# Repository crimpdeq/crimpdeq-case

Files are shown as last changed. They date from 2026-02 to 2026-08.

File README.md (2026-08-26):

# Crimpdeq 3D Case

OpenSCAD source files for the Crimpdeq 3D-printable enclosure (main body + lid), including assembly models and collision checks used in CI.

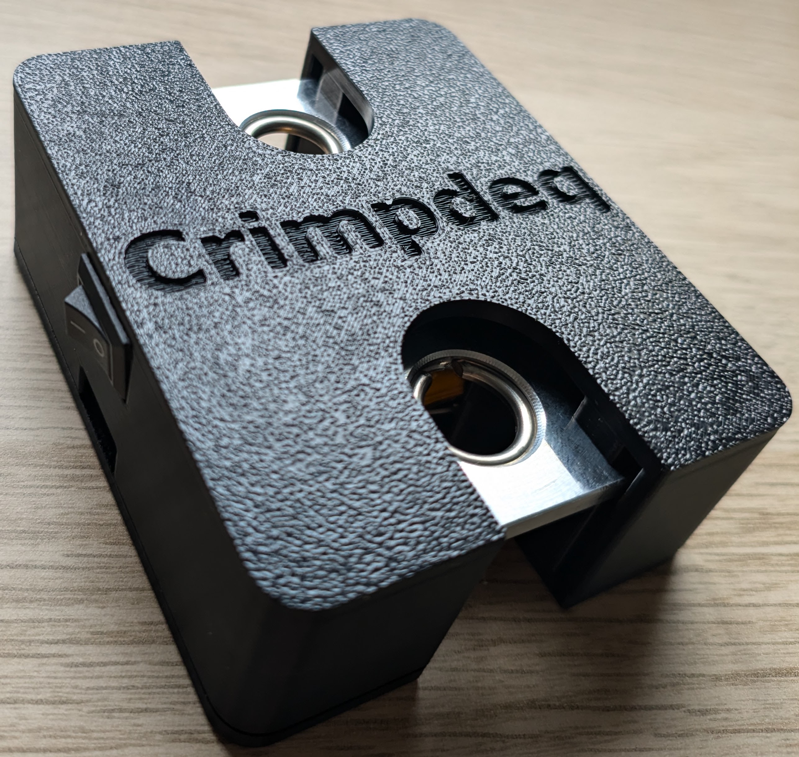
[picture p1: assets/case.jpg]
Crimpdeq 3D Case


The repository contains:

- Parametric OpenSCAD models for the enclosure under `case/`
- Component envelope models (PCB, battery, load cell)
- Collision/fit validation script (`scripts/check-collisions.sh`)
- GitHub Actions workflows that build STL artifacts and release assets

Prebuilt STL files are published in [GitHub Releases](https://github.com/crimpdeq/crimpdeq-case/releases) for tagged versions.

## Components

- [Crimpdeq PCB](https://github.com/crimpdeq/crimpdeq-pcb/releases/latest)
- [2000mAh battery](https://www.aliexpress.us/item/3256809404408618.html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)
- [KCD11 switch](https://www.aliexpress.us/item/2255800787248498.html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)
- Load cell from this [hanging scale](https://www.aliexpress.us/item/3256802533330674.html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)

## Requirements

- `openscad` (CLI and/or GUI)
- `bash`
- Optional for headless Linux runs: `xvfb-run` (the collision script uses it automatically when no `DISPLAY` is available)

## Quick Start

### Preview in OpenSCAD (GUI)

Open the main files directly:

```bash
openscad case/case_main.scad
openscad case/case_lid.scad
openscad case/assembly.scad
```

### Export STL files (CLI)

```bash
openscad -o case/case_main.stl case/case_main.scad
openscad -o case/case_lid.stl case/case_lid.scad
```

By default, both files export in assembly orientation:
- `case_main.scad`: main body in assembled orientation
- `case_lid.scad`: lid in assembled orientation

To export in print layout instead:

```bash
openscad -D 'print_layout=true' -o /tmp/case_main_print_layout.stl case/case_main.scad
openscad -D 'print_layout=true' -o /tmp/case_lid_print_layout.stl case/case_lid.scad
```

Print layout places:
- `case_main.scad`: upright with the floor on the build plate (`Z=0`)
- `case_lid.scad`: flipped so the outer top face is on the build plate (support-free)

### Run collision checks

This validates expected contacts/clearances between the enclosure parts and the internal components, including a USB-C cable plug housing fit check at the port opening.

```bash
bash scripts/check-collisions.sh
```

Useful overrides for faster/local runs:

```bash
CHECK_JOBS=4 OPENSCAD_RENDER_FN=24 bash scripts/check-collisions.sh
```

- `CHECK_JOBS`: number of OpenSCAD checks to run in parallel (defaults to up to 4 cores)
- `OPENSCAD_RENDER_FN`: tessellation used by collision checks only (defaults to `24`)

## Project Structure

- `case/case_main.scad`: main enclosure body
- `case/case_lid.scad`: lid
- `case/assembly.scad`: combined internal assembly preview (load cell, battery, PCB, switch)
- `case/collision_check.scad`: geometry intersections used for automated collision checks
- `case/dimensions.scad`: shared dimensions and clearances
- `scripts/check-collisions.sh`: CI/local collision validation script

## CI and Releases

- `.github/workflows/cad_ci.yml`
  - Runs collision checks
  - Builds `case_main.stl` and `case_lid.stl`
  - Uploads STL artifacts for CI runs
- `.github/workflows/release.yml`
  - Builds release STL files when a GitHub Release is created
  - Uploads the generated STL files to the release assets

## License

This repository is source-available for personal and educational use only.

Commercial manufacture, sale of PCBs, sale of 3D-printed cases, kits, or assembled Crimpdeq devices requires prior written permission.

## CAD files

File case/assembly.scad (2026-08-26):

//
// Crimpdeq assembly: load cell + battery + PCB
// Units: mm
//

use <load_cell.scad>
use <battery.scad>
use <pcb.scad>
include <placement.scad>

render_fn = is_undef(render_fn) ? 96 : render_fn;
$fn = render_fn;

loadcell_y_max = lc_W / 2;
switch_y_min = switch_y - switch_d / 2;
switch_top_z = switch_z + switch_h_eff / 2;

assert(switch_y_min >= loadcell_y_max,
    str("Switch overlaps load cell by ", loadcell_y_max - switch_y_min, " mm (Y)."));
assert(switch_top_z <= pcb_bottom_z,
    str("Switch overlaps PCB by ", switch_top_z - pcb_bottom_z, " mm (Z)."));

module loadcell_model() {
    color("silver")
        linear_extrude(height = lc_T, center = true)
            loadcell_2d();
}

module switch_model() {
    color("red")
        rotate([0, switch_rot_y, 0])
            cube([switch_w, switch_d, switch_h], center = true);
}

module full_assembly(show_pcb = true) {
    translate([0, 0, loadcell_center_z])
        loadcell_model();

    // Battery laying flat on top of the load cell.
    translate([0, battery_y_offset, loadcell_top_z + loadcell_to_battery_gap + bat_T/2])
        battery_model(rounded = true);

    if (show_pcb)
        // PCB laying flat on top of the battery.
        translate([0, pcb_y_offset, loadcell_top_z + loadcell_to_battery_gap + bat_T + battery_to_pcb_gap + pcb_T/2])
            pcb_model(show_usb = true);

    // Side switch inside enclosure.
    translate([switch_x, switch_y, switch_z])
        switch_model();
}

full_assembly();

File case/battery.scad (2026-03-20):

//
// Battery model (simple envelope)
// Units: mm
//

include <dimensions.scad>

render_fn = is_undef(render_fn) ? 64 : render_fn;
$fn = render_fn;

// Optional: small corner rounding for nicer preview (set to 0 for plain cube)
bat_corner_r = 2;

module battery_model(rounded=true) {

    if (!rounded || bat_corner_r <= 0) {
        // Simple rectangular block
        color("gray")
            cube([bat_W, bat_L, bat_T], center=true);
    } else {
        // Rounded rectangular block (slower but nicer)
        color("gray")
        minkowski() {
            cube([bat_W - 2*bat_corner_r,
                  bat_L - 2*bat_corner_r,
                  bat_T - 2*bat_corner_r], center=true);
            sphere(r=bat_corner_r);
        }
    }
}

// Render battery
battery_model(rounded=true);

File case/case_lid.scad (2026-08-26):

//
// Lid enclosure part
// - corner screw holes aligned with case_main.scad
// - U cutouts aligned with main part for load-cell hole access
// - load-cell vertical hold-down features
//

include <placement.scad>

render_fn = is_undef(render_fn) ? 96 : render_fn;
$fn = render_fn;

/*** Enclosure parameters ***/
wall_t = 3;
lid_t = 3;
corner_r = 6;

eye_access_clear = 1.0;
u_cutout_clear = 2.0;

loadcell_hold_down_clear = 0.6;
loadcell_hold_down_w = 22.6;
loadcell_hold_down_d = 8;
loadcell_hold_down_wall_clear = 0.4;
// Baseline inner-edge placement controls where hold-downs start toward the center.
// Nudged outward slightly to add more battery-side assembly clearance.
loadcell_hold_down_edge_offset = 10.8;
loadcell_hold_down_y_offset = 8;

screw_clear_d = 3.0; // slightly looser clearance so the lid seats more easily on the posts
screw_hole_lead_in_d = 3.8; // underside funnel for easier post entry during assembly
screw_hole_lead_in_depth = 1.0;
screw_head_d = 5.2; // typical M2.5 button/pan head clearance
screw_head_recess = 1.8; // recess depth so heads do not protrude
screw_fit_shank_d = 2.6; // fit-check envelope for an M2.5 screw shank through the lid
screw_fit_head_d = 5.0; // fit-check envelope for a typical M2.5 pan/button head
screw_fit_head_h = 1.6;

// Alignment tabs (underside) that register in the main cavity.
// Intentionally only on front/rear walls so the side U-access zone stays clear.
align_lip_enable = true;
align_lip_h = 1.2;
align_lip_t = 1.0;
align_lip_clear = 0.6; // extra fit margin for print tolerances / elephant foot
align_lip_front_back_len = 24;

// Battery anti-slip tabs on lid underside (engage battery front corners when assembled).
// Placed outside PCB width so they can extend down without colliding with the PCB.
battery_front_stop_enable = true;
battery_front_stop_t = 1.2;
battery_front_stop_w = 3.0;
battery_front_stop_x_inset = 0.5;
battery_front_stop_y_clear = 0.3;
battery_front_stop_z_overlap = bat_T / 2; // reach about mid battery thickness

// Battery side walls (lid underside), running parallel to battery length.
battery_side_wall_enable = true;
battery_side_wall_t = 1.2;
battery_side_wall_clear = 0.7;
// Overlap into the remaining lid roof so battery walls merge with U-cutout corners.
battery_side_wall_u_bridge_overlap = 0.6;

internal_feature_embed = 0.15; // overlap underside features into the roof for a fused STL

status_led_view_d = 2.6;
rgb_led_view_d = 3.0;
led_view_chamfer_depth = 0.8;
led_view_chamfer_delta = 0.6;

brand_text = "Crimpdeq";
brand_font = "Inter:style=Bold";
brand_size = 9.5;
brand_depth = 0.8;
print_layout = false; // true: flip lid for support-free printing (outer top face on bed)

/*** Derived placement ***/
inner_x_min = -lc_L / 2 - clear_x;
inner_x_max = lc_L / 2 + clear_x;

inner_y_min = -pcb_L / 2 - rear_clear;
usb_front_y = pcb_L / 2; // connector flush with PCB edge (no overhang)
inner_y_max = usb_front_y + front_clear;

inner_z_max = pcb_top_z + top_clear;

outer_x_min = inner_x_min - wall_t;
outer_x_max = inner_x_max + wall_t;
outer_y_min = inner_y_min - wall_t;
outer_y_max = inner_y_max + wall_t;
outer_z_max = inner_z_max;

lid_z_min = outer_z_max;
lid_z_max = lid_z_min + lid_t;
brand_y = 0; // centered between U cutouts

hold_down_target_z = loadcell_top_z + loadcell_hold_down_clear;
hold_down_h = lid_z_min - hold_down_target_z;
hold_down_inner_x = lc_L / 2 - loadcell_hold_down_edge_offset - loadcell_hold_down_w / 2;
hold_down_outer_x = inner_x_max - loadcell_hold_down_wall_clear;
hold_down_w = hold_down_outer_x - hold_down_inner_x;
hold_down_x = (hold_down_inner_x + hold_down_outer_x) / 2;

eye_x1 = -lc_L / 2 + eye_center_offset;
eye_x2 = lc_L / 2 - eye_center_offset;
eye_access_d = eye_d + eye_access_clear;
u_cutout_z_d = eye_access_d + 2 * u_cutout_clear;
u_cutout_z_r = u_cutout_z_d / 2;
u_cutout_y_span = lc_W;

screw_x1 = outer_x_min + screw_corner_inset;
screw_x2 = outer_x_max - screw_corner_inset;
screw_y1 = outer_y_min + screw_corner_inset;
screw_y2 = outer_y_max - screw_corner_inset;
head_recess_depth = max(0, min(screw_head_recess, lid_t - 0.6));
align_lip_h_eff = align_lip_enable ? max(0, min(align_lip_h, top_clear - 0.4)) : 0;
battery_front_stop_x = bat_W / 2 - battery_front_stop_x_inset - battery_front_stop_w / 2;
battery_front_stop_y = battery_front_y + battery_front_stop_y_clear + battery_front_stop_t / 2;
battery_front_stop_h = battery_front_stop_enable
    ? max(0, lid_z_min - (battery_top_z - battery_front_stop_z_overlap))
    : 0;
battery_side_wall_x = bat_W / 2 + battery_side_wall_clear + battery_side_wall_t / 2;
// Keep wall span within the hold-down column envelope.
battery_side_wall_l = 2 * loadcell_hold_down_y_offset + loadcell_hold_down_d;
// Extend through the lid thickness so the U-cutout top gap is closed.
battery_side_wall_h = lid_z_max - hold_down_target_z;
battery_side_wall_inner_x = battery_side_wall_x - battery_side_wall_t / 2;
u_cutout_inner_x = eye_x2 - u_cutout_z_r;
battery_side_wall_u_bridge_x0 = u_cutout_inner_x - battery_side_wall_u_bridge_overlap;
battery_side_wall_u_bridge_w = battery_side_wall_inner_x - battery_side_wall_u_bridge_x0;
status_led_view_x = status_led_x;
status_led_view_y = pcb_y_offset + status_led_y;
rgb_led_view_x = rgb_led_x;
rgb_led_view_y = pcb_y_offset + rgb_led_y;
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

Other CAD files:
case/case_main.scad
case/collision_check.scad
case/dimensions.scad
case/enclosure_lid.scad
case/enclosure_main.scad
case/load_cell.scad
case/pcb.scad
case/placement.scad

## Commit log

2026-02-25 feat: Initial commit
    [assembly.scad, battery.scad, collision_check.scad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]
2026-02-27 feat: Add battery walls
    [enclosure_lid.scad, enclosure_main.scad]
2026-02-27 feat: Reduce the gap pbetween floor and loadcell
    [dimensions.scad]
2026-02-27 feat: Close gap between loadcell support and walls
    [enclosure_main.scad]
2026-02-27 feat: Close the gap between the loadcell and the case
    [enclosure_main.scad]
2026-02-27 feat: Close the gap between the loadcell hold downs and the case
    [enclosure_lid.scad]
2026-02-27 feat: Readjust USB-C connector and leave more space between lid and pcb
    [dimensions.scad, enclosure_lid.scad, enclosure_main.scad]
2026-02-27 feat: FIll the gap between battery walls and lid
    [enclosure_lid.scad]
2026-02-27 feat: Remove the usb-c hole on the lid
    [enclosure_lid.scad]
2026-02-27 feat: Make the usb-c hole 12 mm wide
    [enclosure_main.scad]
2026-02-27 feat: Update default position of the lid
    [enclosure_main.scad]
2026-02-27 feat: Improvements and rename
    [case_lid.scad, case_main.scad, collision_check.scad]
2026-02-27 feat: Use small tongue for battery vertical support
    [case_lid.scad, case_main.scad]
2026-03-02 feat: Add crimpdeq.com engraving
    [case_main.scad]
2026-03-09 fix: adjust USB opening for printability
    [case_main.scad]
2026-03-09 feat: add USB opening lead-in chamfer
    [case_main.scad]
2026-03-10 feat: Add usb-c check
    [case_main.scad, collision_check.scad, dimensions.scad]
2026-03-10 fix: center USB cable fit probe extrusion
    [case_main.scad]
2026-03-10 fix: refine USB opening profile
    [case_main.scad]
2026-03-10 perf: speed up collision checks
    [assembly.scad, battery.scad, case_lid.scad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]
2026-03-20 fix: improve lid closure fit
    [case_lid.scad]
2026-03-27 fix: raise usb-c opening for easier insertion
    [case_main.scad]
2026-04-09 fix: improve pcb support and drop-in assembly
    [case_main.scad, dimensions.scad]
2026-08-26 Revision 2 (#4)
    * feat: add RGB LED lid viewing hole
    * refactor: share component placement
    * fix: match PCB v2 board outline
    * fix: embed internal supports into shell
    * feat: chamfer LED viewing holes
    * perf: gate preview-only geometry
    * test: validate LED sightlines and STL connectivity
    * docs: Update PCB link
    * test: check lid closure and screw fit
    * ci: include commit SHA in STL artifacts
    * fix: increase battery tongue load-cell clearance
    [assembly.scad, case_lid.scad, case_main.scad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]
2026-10-18 Revision 3 (#11)
    * feat: tighten usb-c case opening
    * feat: add pcb top clamps
    * fix: move pcb clamps away from wire pads
    * fix: keep pcb clamps away from wire pads
    * fix: match pcb edge dimensions
    * feat: update enclosure for PCB revision 3
    Adapt the case, USB-C access, LED sightlines, and PCB retention to the revised board while preserving printable connected solids.
    * feat: enclose compact load-cell pod
    Shrink the enclosure around the revised electronics while sealing the internals and preserving isolated access for both carabiners.
    * feat: reduce compact pod dimensions
    Trim shell t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
2026-10-18 fix: stop the lid slot walls wedging into the facets (#12)
    * feat: r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
2026-10-18 fix: clamp the battery so it cannot rattle (#13)
    * fix: clamp the battery so it cannot rattle
    Nothing in the lid sat over the battery behind the PCB, so flipping the
    case let its rear swing up to 6.8 mm to the lid, and nothing held it on
    its rear pads, so it also slid within its guides.
    - Add lid hold-downs directly above the battery's rear pads that press it
    by one 0.2 mm layer. The clamp load goes into the floor, not the load
    cell, and the hold-downs stay inside the board's width, clear of the
    battery leads.
    - Share the pad footprint and box() through dimensions.scad and
    placement.scad so the main body and lid use the same values.
    - Check that the hold-downs press the battery, by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
2026-10-19 docs: lead the readme with printing and compatibility; release STLs in print layout (#15)
    * ci: release the case STLs in print layout
    * docs: lead the readme with printing, compatibility, and V3 links
    * docs: state the V1 exception to major-version compatibility
    * docs: point to the book for assembly and drop the design section
    * docs: point each PCB revision to its case release
2026-10-20 Show the V3 case photo in the readme (#16)
    * docs: show the V3 case photo in the readme
    * docs: show the V3 photo first and label both case photos
2026-10-20 docs: vendor the V3 case photo
2026-11-05 feat: fit the 102530 battery and shrink the case to 103.3 x 77.4 x 25.5 mm (#18)
    * feat: fit the 800 mAh battery and lower the case by 4 mm
    The 6 x 30 x 42 mm battery replaces the 10 x 34 x 50 mm one, so the stack
    and the case are 4 mm lower (26.6 mm). Its rear pads stay just behind the
    load cell; the shorter battery no longer reaches the PCB columns, so they
    stop in front of the load cell, the battery-front rib is gone and the lid
    clamp holds it. The bay wall stays put, leaving room beside the battery for
    its leads.
    * refactor: move the PCB column clearance into the shared sources
    * feat: fit the 102530 battery and a snap-in rocker switch
    The 800 mAh 102530 battery (10 x 25 x 30 mm) rep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
2026-11-12 fix: use the measured 13.9 mm eye-ring bore (#19)
    The pressed-in eye rings measure 13.8-13.9 mm, not 15 mm. The bore only feeds the carabiner fit checks, so the case geometry does not change.
2026-11-13 feat: redesign the case for the tscircuit board (#17)
    * feat: redesign the case for the tscircuit board
    Replace the V3 hexagonal case with a smaller one for the crimpdeq-tscircuit
    board (17 x 31.5 mm), a 603040 battery (6 x 30 x 42 mm), the same KCD11
    switch and load cell, and M2.5x10 screws. It is 90 x 58 x 25 mm, down from
    97.1 x 77.4 x 30.6 mm.
    - Put the load cell in with its gauge cover down on 3 mm floor pads, so the
    battery lies flat on the bare plate and the stack drops 5.6 mm. Lid bars
    stop 0.3 mm above the battery, so nothing presses it onto the load cell.
    - Place the board top side up and unrotated over the battery, with its wire-pad
    end and USB-C connector in a front band,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
